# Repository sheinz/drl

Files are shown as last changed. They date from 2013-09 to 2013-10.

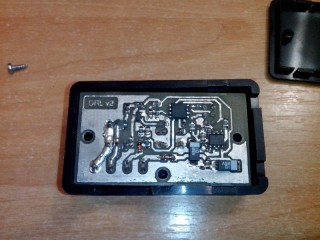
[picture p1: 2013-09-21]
doc/drl_3.jpg

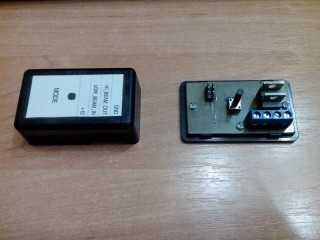
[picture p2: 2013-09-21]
doc/drl_1.jpg

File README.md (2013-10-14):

drl
===

Daytime running lamp controller. Use standard high beam lamps with reduced power to implemen daytime running lamps.
The controller is implemented using ATMEL ATTiny13A microcontroller.
It uses PWM to control lamp brightness. 



**Features:**
- Use PWM to control hi beam lamp power.
- Automatically turns on after engine is started. Detects voltage increase to determine if engine is running.
- Automatically turns off when low beam lamps is on.
- Provides DRL brightness configuration by clicking a switch. Each click slightly increases brightness.
- The brightness of the DRL is stored in EEPROM. 
- Can be completely disabled by configurin brightness that equal zero.
- If a device is malfunctioning it records errors and blinks hi beam lamps at start. 
- The error count is cleared after clicking a switch.

**Build**

In order to build the source code the following packages should be installed:

    sudo apt-get install gcc-avr
    sudo apt-get install avr-libc
    sudo apt-get install cmake
    
If you encounter errors like these:
    
    ld: crttn13a.o: No such file: No such file or directory
    undefined reference to `__eerd_byte_tn13a'
    
Copy libraries crttn13a.o and libc.a into tiny-stack subdirectory:

    sudo cp /usr/lib/avr/lib/avr25/crttn13a.o /usr/lib/avr/lib/avr25/tiny-stack/
    sudo cp /usr/lib/avr/lib/avr25/libc.a /usr/lib/avr/lib/avr25/tiny-stack/
    
To build and upload the firmware:
    
    mkdir drl-build
    cd drl-build
    cmake ../drl
    make
    make upload

--------------








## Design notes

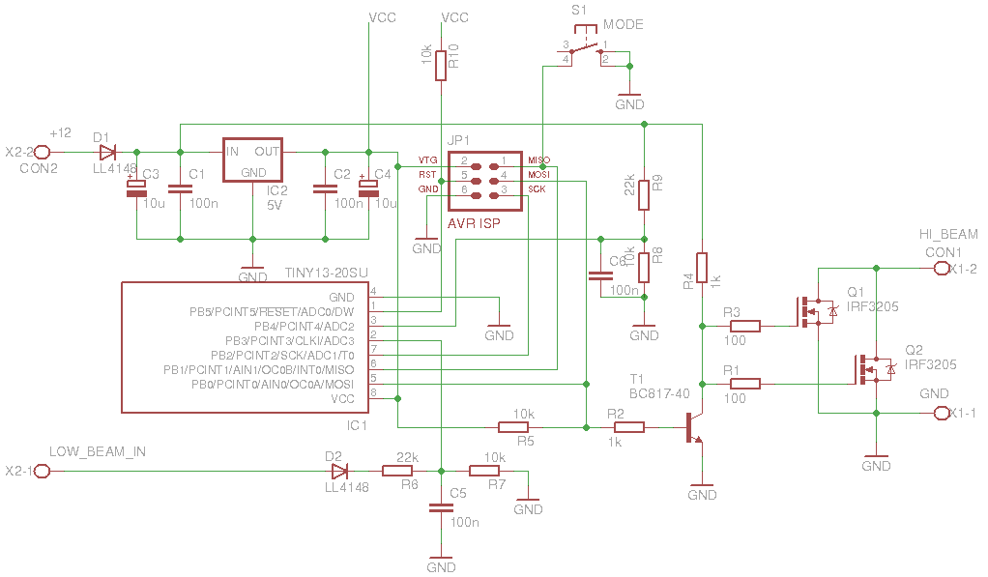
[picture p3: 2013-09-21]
doc/schematic.png

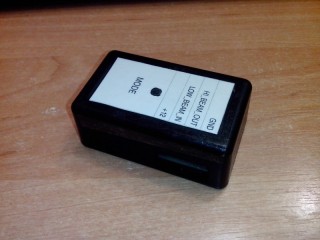
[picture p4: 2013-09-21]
doc/drl_4.jpg

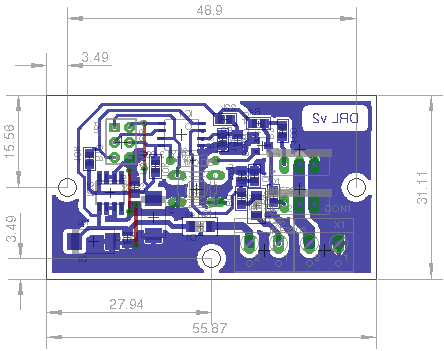
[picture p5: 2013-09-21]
doc/pcb.png

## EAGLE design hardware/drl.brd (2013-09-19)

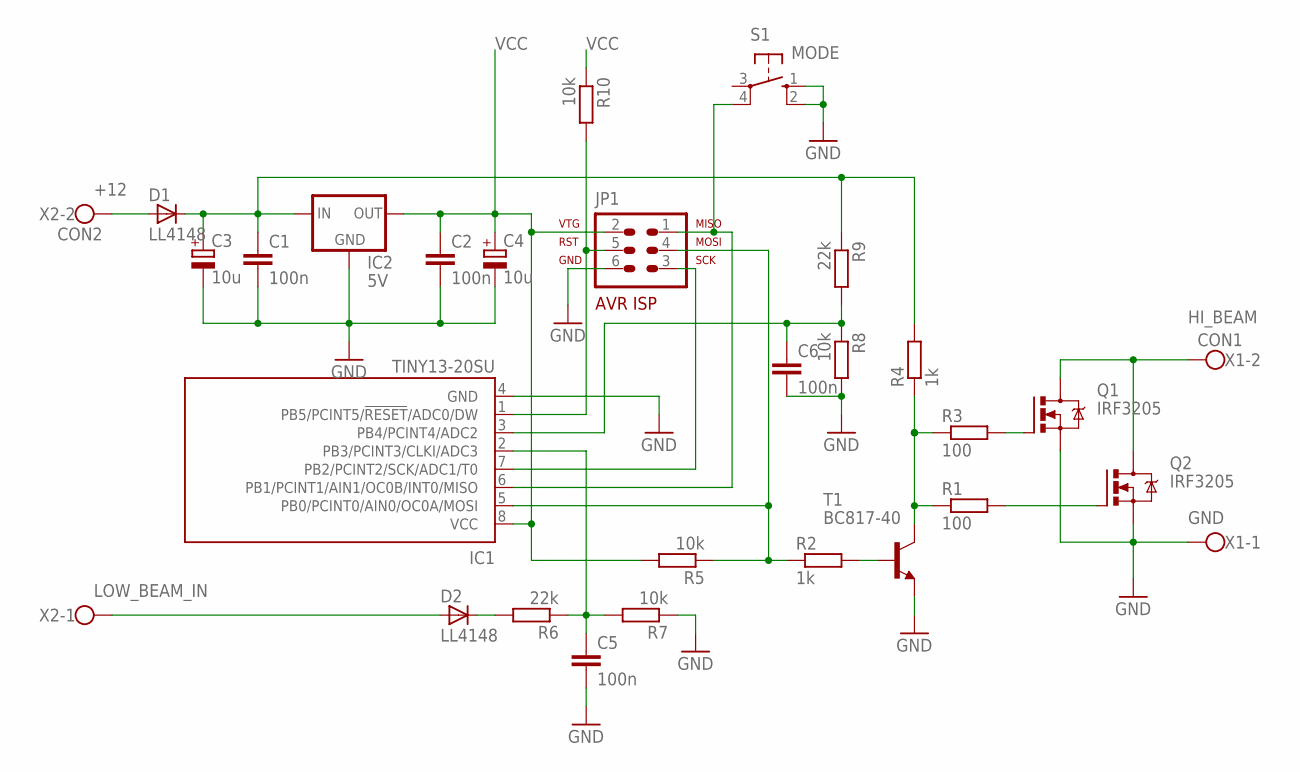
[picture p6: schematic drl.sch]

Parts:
C1, C2, C5, C6: 100n; C0805K
C3, C4: 10u; SMC_D
D1, D2: LL4148; SOD80
IC1: TINY13-20SU; 8S2
IC2: 5V; SOIC8
JP1: AVR-ISP-6
Q1, Q2: IRF3205; TO220BV
R1, R3: 100; R0805
R2: 1k; 0204/7
R4: 1k; R0805
R5, R7, R8, R10: 10k; R0805
R6, R9: 22k; R0805
S1: MODE; B3F-10XX
T1: BC817-40; SOT23-BEC
X1: CON1; W237-102
X2: CON2; W237-102

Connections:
+12: D1.2 (A), X2.2
GND: C1.2, C2.2, C3.-, C4.-, C5.2, C6.2, IC1.4 (GND), IC2.2 (GND), IC2.3 (GND), IC2.6 (GND), IC2.7 (GND), JP1.6, Q1.S, Q2.S, R7.1, R8.2, S1.1 (S), S1.2 (S1), T1.E, X1.1
HI_BEAM: Q1.D, Q2.D, X1.2
LOW_BEAM_IN: D2.2 (A), X2.1
unnamed: Q2.G, R1.2
unnamed: D2.1 (C), R6.2
unnamed: Q1.G, R3.2
unnamed: IC1.7 (PB2/PCINT2/SCK/ADC1/T0), JP1.3
unnamed: R2.2, T1.B
unnamed: R1.1, R3.1, R4.1, T1.C
unnamed: C5.1, IC1.2 (PB3/PCINT3/CLKI/ADC3), R6.1, R7.2
unnamed: IC1.1 (PB5/PCINT5/!RESET!/ADC0/DW), JP1.5, R10.2
unnamed: IC1.5 (PB0/PCINT0/AIN0/OC0A/MOSI), JP1.4, R2.1, R5.1
unnamed: IC1.6 (PB1/PCINT1/AIN1/OC0B/INT0/MISO), JP1.1, S1.4 (P1)
unnamed: C6.1, IC1.3 (PB4/PCINT4/ADC2), R8.1, R9.2
VCC: C2.1, C4.+, IC1.8 (VCC), IC2.1 (OUT), JP1.2, R5.2, R10.1
VCC12: C1.1, C3.+, D1.1 (C), IC2.8 (IN), R4.2, R9.1

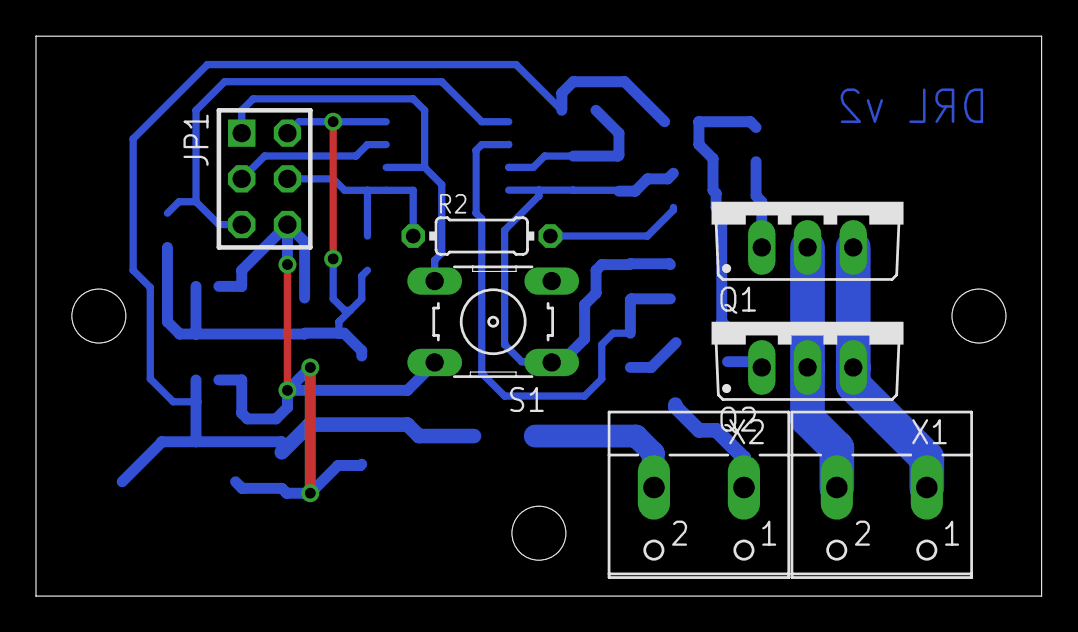
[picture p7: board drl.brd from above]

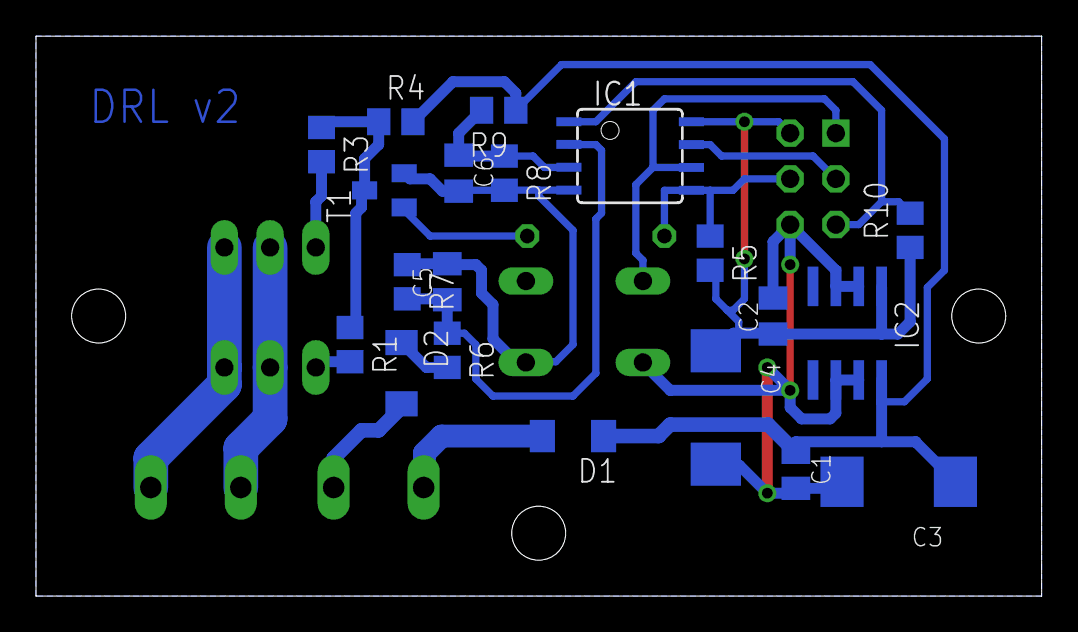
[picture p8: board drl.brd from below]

Board: 2 copper layers, 55.9 x 31.1 mm, 27 parts (20 on the bottom side), 17 nets.

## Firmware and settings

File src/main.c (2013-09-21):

#include <inttypes.h>

#include <avr/io.h>
#include <avr/eeprom.h>
#include <util/delay.h>
#include <avr/interrupt.h>
#include <avr/wdt.h>


#include "timer.h"
#include "adc.h"


#define SHOW_ERRORS


#define IS_LOW_BEAM_ON (bit_is_clear(PINB, PB3))

#define IS_KEY_PRESSED (bit_is_clear(PINB, PB1))

static uint8_t pwm;
static uint8_t low_beam_on = 0;
static uint8_t key_is_pressed = 0;

EEMEM uint8_t eeprom_pwm = 100;

#ifdef SHOW_ERRORS
   EEMEM uint8_t eeprom_error_count = 0;
#endif

#define PWM_INCREMENT_STEP    20
#define ERROR_RESET_COUNT     0

#define VOLTAGE_THRESHOLD     200      // the DRL should turn on at 13.2 V

int main(void)
{
   wdt_enable(WDTO_2S);

   INIT_ADC();

   // init key
   // PB1 is already an input
   PORTB |= _BV(PB1);      // pull up


#ifdef SHOW_ERRORS
   uint8_t errors = eeprom_read_byte(&eeprom_error_count);
   if (bit_is_set(MCUSR, WDRF) || bit_is_set(MCUSR, EXTRF))
   {
      errors++;
      eeprom_update_byte(&eeprom_error_count, errors);
   }
#endif

   init_timer();

   pwm = eeprom_read_byte(&eeprom_pwm);

   if (IS_LOW_BEAM_ON)     // to trigger first init
   {
      low_beam_on = 0;
   }
   else
   {
      low_beam_on = 1;
   }

#ifdef SHOW_ERRORS
   // indicate errors
   for (uint8_t i = 0; i < errors; i++)
   {
      set_pwm(20);
      sleep_ms(500);
      set_pwm(0);
      sleep_ms(500);
      wdt_reset();
   }
#endif

   while (1)
   {
      if (GET_VOLTAGE() >= VOLTAGE_THRESHOLD)
      {  // Engine is on
         break;
      }
      sleep_ms(100);
      wdt_reset();
   }

	while (1)
	{
	   if (IS_LOW_BEAM_ON)
	   {
	      if (!low_beam_on)
	      {
	         low_beam_on = 1;
	         set_pwm(0);
	      }
	   }
	   else
	   {
	      if (low_beam_on)
	      {
	         low_beam_on = 0;
	         set_pwm(pwm);
	      }
	   }

	   // key processing
	   if (IS_KEY_PRESSED)
	   {
	      if (!key_is_pressed)
	      {
	         key_is_pressed = 1;
	      }
	   }
	   else
	   {
	      if (key_is_pressed)
	      {
	         key_is_pressed = 0;
	         if (0xFF - pwm < PWM_INCREMENT_STEP)
	         {
	            pwm = 0;
	         }
	         else
	         {
	            pwm += PWM_INCREMENT_STEP;
	         }
	         eeprom_update_byte(&eeprom_pwm, pwm);
	         eeprom_update_byte(&eeprom_error_count, 0);
	         set_pwm(pwm);
	      }
	   }

	   sleep_ms(100);
	   wdt_reset();
	}


	return 0;
}

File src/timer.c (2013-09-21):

#include "timer.h"

#ifdef __ECLIPSE_INDEXER_BUG__
   #include <avr/iotn13.h>
#else
   #include <avr/io.h>
#endif

#include <avr/interrupt.h>

static volatile uint32_t sys_ticks;


ISR(TIM0_OVF_vect)
{
   sys_ticks += 8;   // timer overflows every 8 ms
}

void init_timer(void)
{
   // Set OC0A pin to output
   PORTB |= _BV(PB0);    // pull it high before switching to output
   DDRB |= _BV(PB0);

   // Clear OC0A on Compare Match, set OC0A at TOP (inverted mode)
   // Inverted mode is used in order to remove narrow spikes in OFF mode.
   // Fast PWM mode
   TCCR0A = _BV(COM0A1) | _BV(WGM00) | _BV(WGM01);

   OCR0A = 0xFF;     // initial state OFF (inverted)

   // Prescaler CLK/256
   TCCR0B = _BV(CS02);

   sys_ticks = 0;

   TIMSK0 = _BV(TOIE0);

   sei();
}

void set_pwm(uint8_t duty)
{
   OCR0A = 255 - duty;
}

uint32_t get_ticks(void)
{
   uint32_t mseconds;
   uint8_t sreg = SREG;

   cli();

   mseconds = sys_ticks;

   SREG = sreg;

   return mseconds;
}

void sleep_ms(uint32_t mseconds)
{
   uint32_t startTime = get_ticks();

   while ( (startTime + mseconds) > get_ticks() );
}

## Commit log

2013-09-09 Initial schematic and board design
    [drl.brd, drl.sch]
2013-09-09 Made the board slightly shorter. More compact component placement.
    [drl.brd]
2013-09-09 Added ground plane
    [drl.brd]
2013-09-14 Added draft implementation of pwm
2013-09-14 Change in schematic and board.
    [drl.brd, drl.sch]
2013-09-14 Saving PWM into EEPROM
2013-09-14 Resistor value was edited
    [drl.brd, drl.sch]
2013-09-14 Add watch dog timer and error indication at power on
    [main.c]
2013-09-19 Second version of hardware (schematic and pcb)
    [drl.brd, drl.sch]
2013-09-19 Small editions in schematic and board design.
    [drl.brd, drl.sch]
2013-09-19 The dimentions were adjusted to fit the case
    [drl.brd]
2013-09-21 New version. Added switch support. Turn on when engine is started measuring voltage
2013-09-21 Added pictures of the device
2013-09-21 Add schematic and pcb as images
2013-10-13 Switched to CMake build system
